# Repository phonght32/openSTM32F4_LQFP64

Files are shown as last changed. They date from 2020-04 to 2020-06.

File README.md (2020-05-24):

# openSTM32F4_LQFP64

### 1. Overview

Everything about this board: schematic, PCB gerber and BOM are free to distribute under open-source license for users.

The STM32F4 series chip inside openSTM32 board is based on ARM Cortex-M4 with floating point unit (FPU).

### 2. Specifications

| Items | Specifications |
| --- | --- |
| Power supply | 5V micro USB<br />5~36V Jack DC |
| Microcontroller | STM32F405RGT6 / 32-bit ARM Cortex-M4 with FPU(168MHz, 225DMIPS) |
| Sensors | 3 axis gyroscope, 3 axis accelerometer, 3 axis magnetometer (MPU9250) |
| Programmer | JTAG/SWD connector<br />Serial (UART3) |
| Communicaton Ports  | UART x 3<br />I2C x 1<br />SPI x 1 |
| Multimedia | I2S x 1 |
| Analog input | ADC channel x 5 |
| Analog output | DAC channel x 1 |
| PWM | Timer PWM x 4 |
| Leds and buttons | D7 and D8: USB communication<br />D6: 3V3 power on<br />D1: USER LED status<br />SW2: Reset button<br />SW1: USER button |
| Digital I/O | 10 pins |
| Output power source | 5V max 3A (TPS5430 step-down converter)<br />3V3 max 1A (AMS1117 linear regulator) |
| Dimensions | 68 x 64 mm |

**NOTE:**

This board auto select power supply when both USB and jackDC are powered.

### 3. Layout / Pin map

### 4. Hardware design

#### Schematic

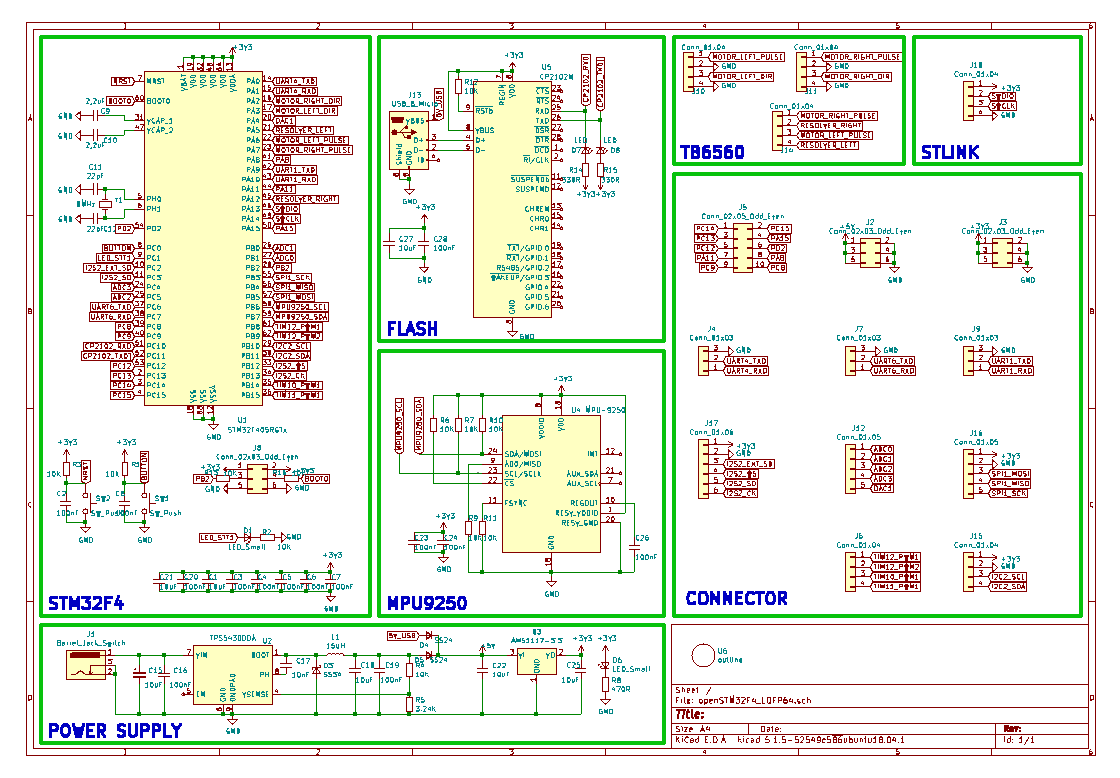
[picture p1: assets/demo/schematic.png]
schematic


#### Dimension

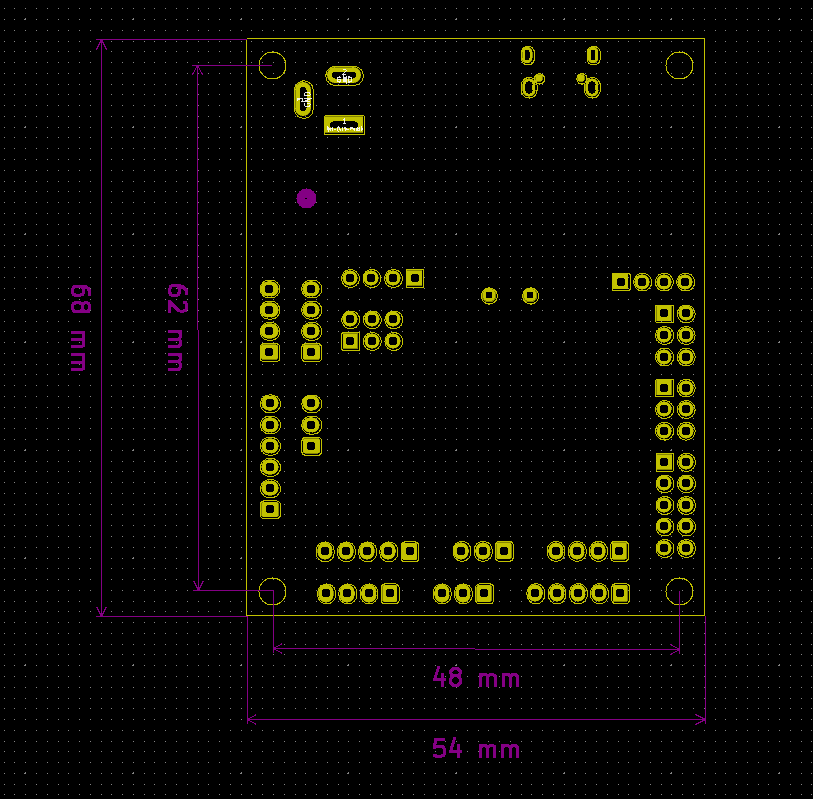
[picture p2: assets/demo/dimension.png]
dimension


#### PCB Top

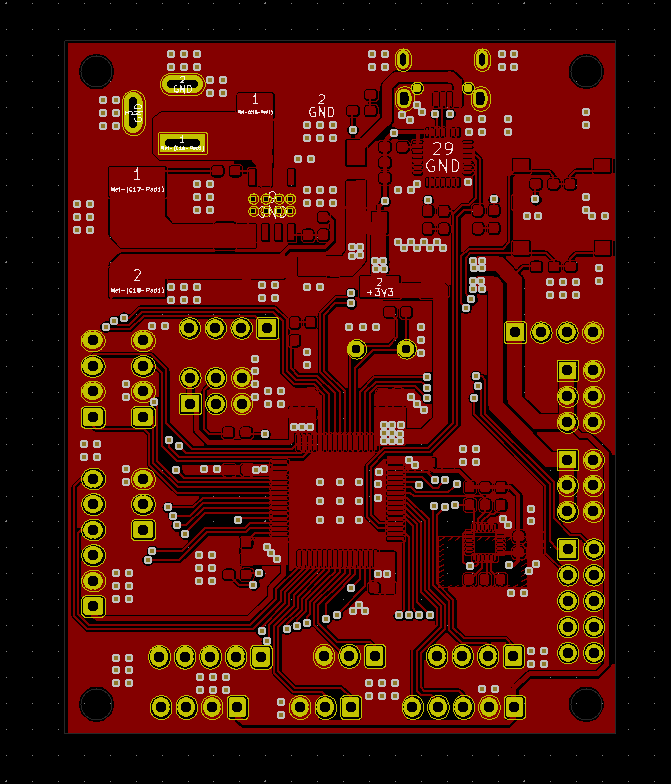
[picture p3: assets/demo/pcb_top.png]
pcb_top


#### PCB Bot

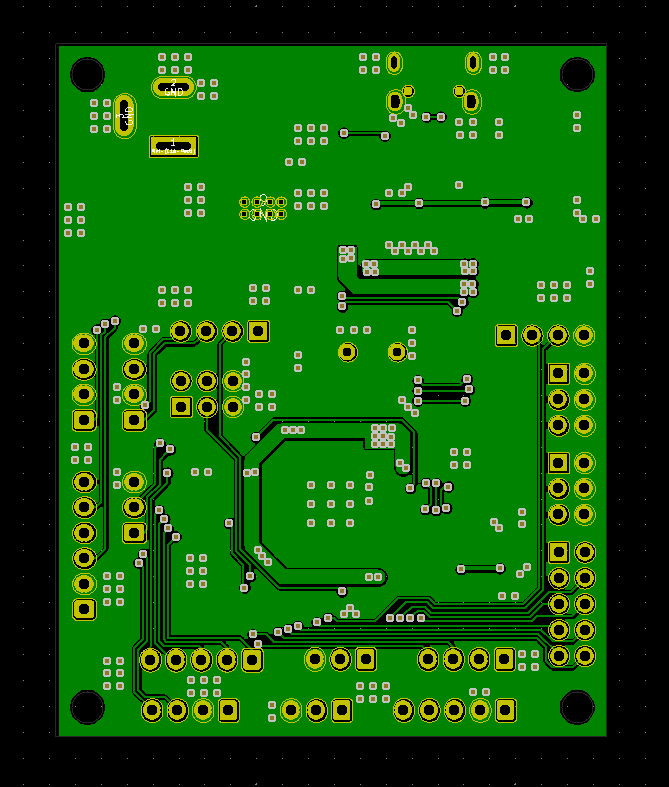
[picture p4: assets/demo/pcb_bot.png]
pcb_bot


#### 3D Top

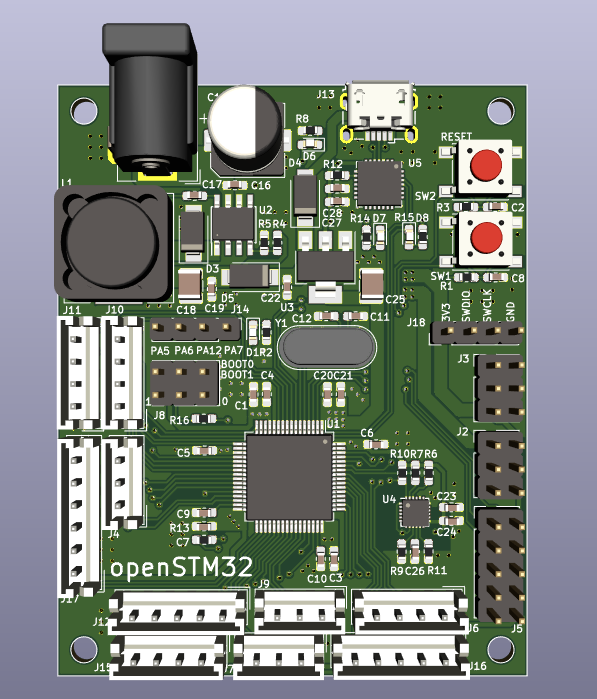
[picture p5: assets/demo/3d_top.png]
3d_top


#### 3D Bot

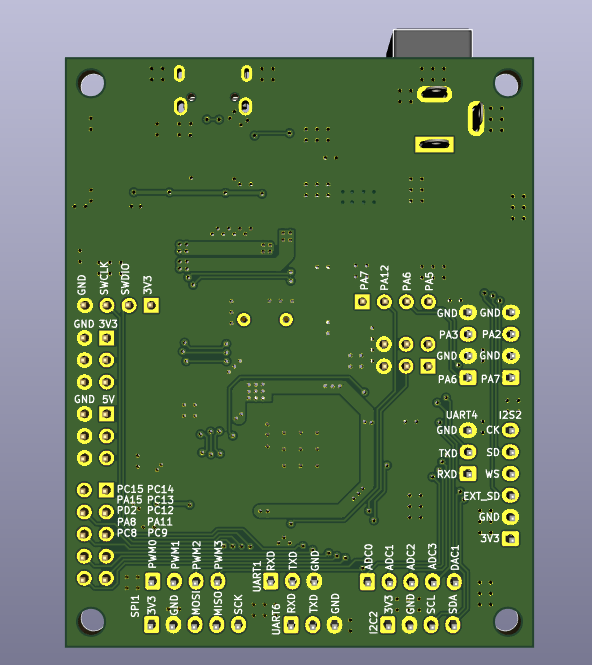
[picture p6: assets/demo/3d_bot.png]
3d_bot


### 5. Bill of Materials (BOM)

Download BOM [here.](assets/bom.xlsx)

### 6. Gerber

Download PCB gerber [here.](assets/openSTM32_68x54mm.zip)

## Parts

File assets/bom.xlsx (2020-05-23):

Source: | /home/phong/Documents/thesis/openSTM32F4_LQFP64/openSTM32F4_LQFP64.sch
Date: | Thứ bảy, 23 Tháng năm Năm 2020 22:04:47 +07
Tool: | Eeschema 5.1.6-c6e7f7d~86~ubuntu16.04.1
Generator: | /usr/share/kicad/plugins/bom_csv_grouped_by_value_with_fp.py
Component Count: | 77
Ref | Qnty | Value | Cmp name | Footprint | Description | Vendor
C1, C21, C22, C27, | 4 | 10uF | C_Small | Capacitor_SMD:C_0603_1608Metric_Pad1.05x0.95mm_HandSolder | Unpolarized capacitor, small symbol
C2, C3, C4, C5, C6, C7, C8, C16, C19, C20, C23, C24, C26, C28, | 14 | 100nF | C_Small | Capacitor_SMD:C_0603_1608Metric_Pad1.05x0.95mm_HandSolder | Unpolarized capacitor, small symbol
C9, C10, | 2 | 2,2uF | C_Small | Capacitor_SMD:C_0603_1608Metric_Pad1.05x0.95mm_HandSolder | Unpolarized capacitor, small symbol
C11, C12, | 2 | 22pF | C_Small | Capacitor_SMD:C_0603_1608Metric_Pad1.05x0.95mm_HandSolder | Unpolarized capacitor, small symbol
C15, | 1 | 10uF | CP_Small | Capacitor_SMD:CP_Elec_8x10 | Polarized capacitor, small symbol
C17, | 1 | 10nF | C_Small | Capacitor_SMD:C_0603_1608Metric_Pad1.05x0.95mm_HandSolder | Unpolarized capacitor, small symbol
C18, C25, | 2 | 10uF | C_Small | Capacitor_SMD:C_1210_3225Metric | Unpolarized capacitor, small symbol
D1, D6, | 2 | LED_Small | LED_Small | LED_SMD:LED_0603_1608Metric_Pad1.05x0.95mm_HandSolder | Light emitting diode, small symbol
D3, | 1 | SS34 | D_Schottky_Small | Diode_SMD:D_SMA | Schottky diode, small symbol
D4, D5, | 2 | SS24 | D_Small | Diode_SMD:D_SMA | Diode, small symbol
D7, D8, | 2 | LED | LED_Small | LED_SMD:LED_0603_1608Metric_Pad1.05x0.95mm_HandSolder | Light emitting diode, small symbol
J1, | 1 | Barrel_Jack_Switch | Barrel_Jack_Switch | Connector_BarrelJack:BarrelJack_Wuerth_6941xx301002 | DC Barrel Jack with an internal switch
J2, J3, J8, | 3 | Conn_02x03_Odd_Even | Conn_02x03_Odd_Even | Connector_PinHeader_2.54mm:PinHeader_2x03_P2.54mm_Vertical | Generic connector, double row, 02x03, odd/even pin numbering scheme (row 1 odd numbers, row 2 even numbers), script generated (kicad-library-utils/schlib/autogen/connector/)
J4, J7, J9, | 3 | Conn_01x03 | Conn_01x03 | Connector_JST:JST_EH_B3B-EH-A_1x03_P2.50mm_Vertical | Generic connector, single row, 01x03, script generated (kicad-library-utils/schlib/autogen/connector/)
J5, | 1 | Conn_02x05_Odd_Even | Conn_02x05_Odd_Even | Connector_PinHeader_2.54mm:PinHeader_2x05_P2.54mm_Vertical | Generic connector, double row, 02x05, odd/even pin numbering scheme (row 1 odd numbers, row 2 even numbers), script generated (kicad-library-utils/schlib/autogen/connector/)
J6, J10, J11, J15, | 4 | Conn_01x04 | Conn_01x04 | Connector_JST:JST_EH_B4B-EH-A_1x04_P2.50mm_Vertical | Generic connector, single row, 01x04, script generated (kicad-library-utils/schlib/autogen/connector/)
J12, J16, | 2 | Conn_01x05 | Conn_01x05 | Connector_JST:JST_EH_B5B-EH-A_1x05_P2.50mm_Vertical | Generic connector, single row, 01x05, script generated (kicad-library-utils/schlib/autogen/connector/)
J13, | 1 | USB_B_Micro | USB_B_Micro | Connector_USB:USB_Micro-B_Wuerth_629105150521 | USB Micro Type B connector
J14, J18, | 2 | Conn_01x04 | Conn_01x04 | Connector_PinHeader_2.54mm:PinHeader_1x04_P2.54mm_Vertical | Generic connector, single row, 01x04, script generated (kicad-library-utils/schlib/autogen/connector/)
J17, | 1 | Conn_01x06 | Conn_01x06 | Connector_JST:JST_EH_B6B-EH-A_1x06_P2.50mm_Vertical | Generic connector, single row, 01x06, script generated (kicad-library-utils/schlib/autogen/connector/)
L1, | 1 | 15uH | L_Small | Inductor_SMD:L_12x12mm_H6mm | Inductor, small symbol
R1, R2, R3, R4, R6, R7, R9, R10, R11, R12, R13, R16, | 12 | 10K | R_Small | Resistor_SMD:R_0603_1608Metric_Pad1.05x0.95mm_HandSolder | Resistor, small symbol
R5, | 1 | 3.24K | R_Small | Resistor_SMD:R_0603_1608Metric_Pad1.05x0.95mm_HandSolder | Resistor, small symbol
R8, | 1 | 470R | R_Small | Resistor_SMD:R_0603_1608Metric_Pad1.05x0.95mm_HandSolder | Resistor, small symbol
R14, R15, | 2 | 330R | R_Small | Resistor_SMD:R_0603_1608Metric_Pad1.05x0.95mm_HandSolder | Resistor, small symbol
SW1, SW2, | 2 | SW_Push | SW_Push | Button_Switch_SMD:SW_Push_1P1T_NO_6x6mm_H9.5mm | Push button switch, generic, two pins
U1, | 1 | STM32F405RGTx | STM32F405RGTx | Package_QFP:LQFP-64_10x10mm_P0.5mm | ARM Cortex-M4 MCU, 1024KB flash, 128KB RAM, 168MHz, 1.8-3.6V, 51 GPIO, LQFP-64
U2, | 1 | TPS5430DDA | TPS5430DDA | Package_SO:TI_SO-PowerPAD-8_ThermalVias | 3A, Step Down Swift Converter, Adjustable Output Voltage, 5.5-36V Input Voltage, PowerSO-8
U3, | 1 | AMS1117-3.3 | AMS1117-3.3 | Package_TO_SOT_SMD:SOT-223-3_TabPin2 | 1A Low Dropout regulator, positive, 3.3V fixed output, SOT-223
U4, | 1 | MPU-9250 | MPU-9250 | Sensor_Motion:InvenSense_QFN-24_3x3mm_P0.4mm | InvenSense 9-Axis Motion Sensor, Accelerometer, Gyroscope, Compass, I2C/SPI
U5, | 1 | CP2102N | CP2102N-A01-GQFN28 | Package_DFN_QFN:QFN-28-1EP_5x5mm_P0.5mm_EP3.35x3.35mm | USB to UART master bridge, QFN-28
U6, | 1 | outline | outline | footprints:openSTM32F4_LQFP64_outline
Y1, | 1 | 8MHz | Crystal_Small | Crystal:Crystal_HC49-4H_Vertical | Two pin crystal, small symbol

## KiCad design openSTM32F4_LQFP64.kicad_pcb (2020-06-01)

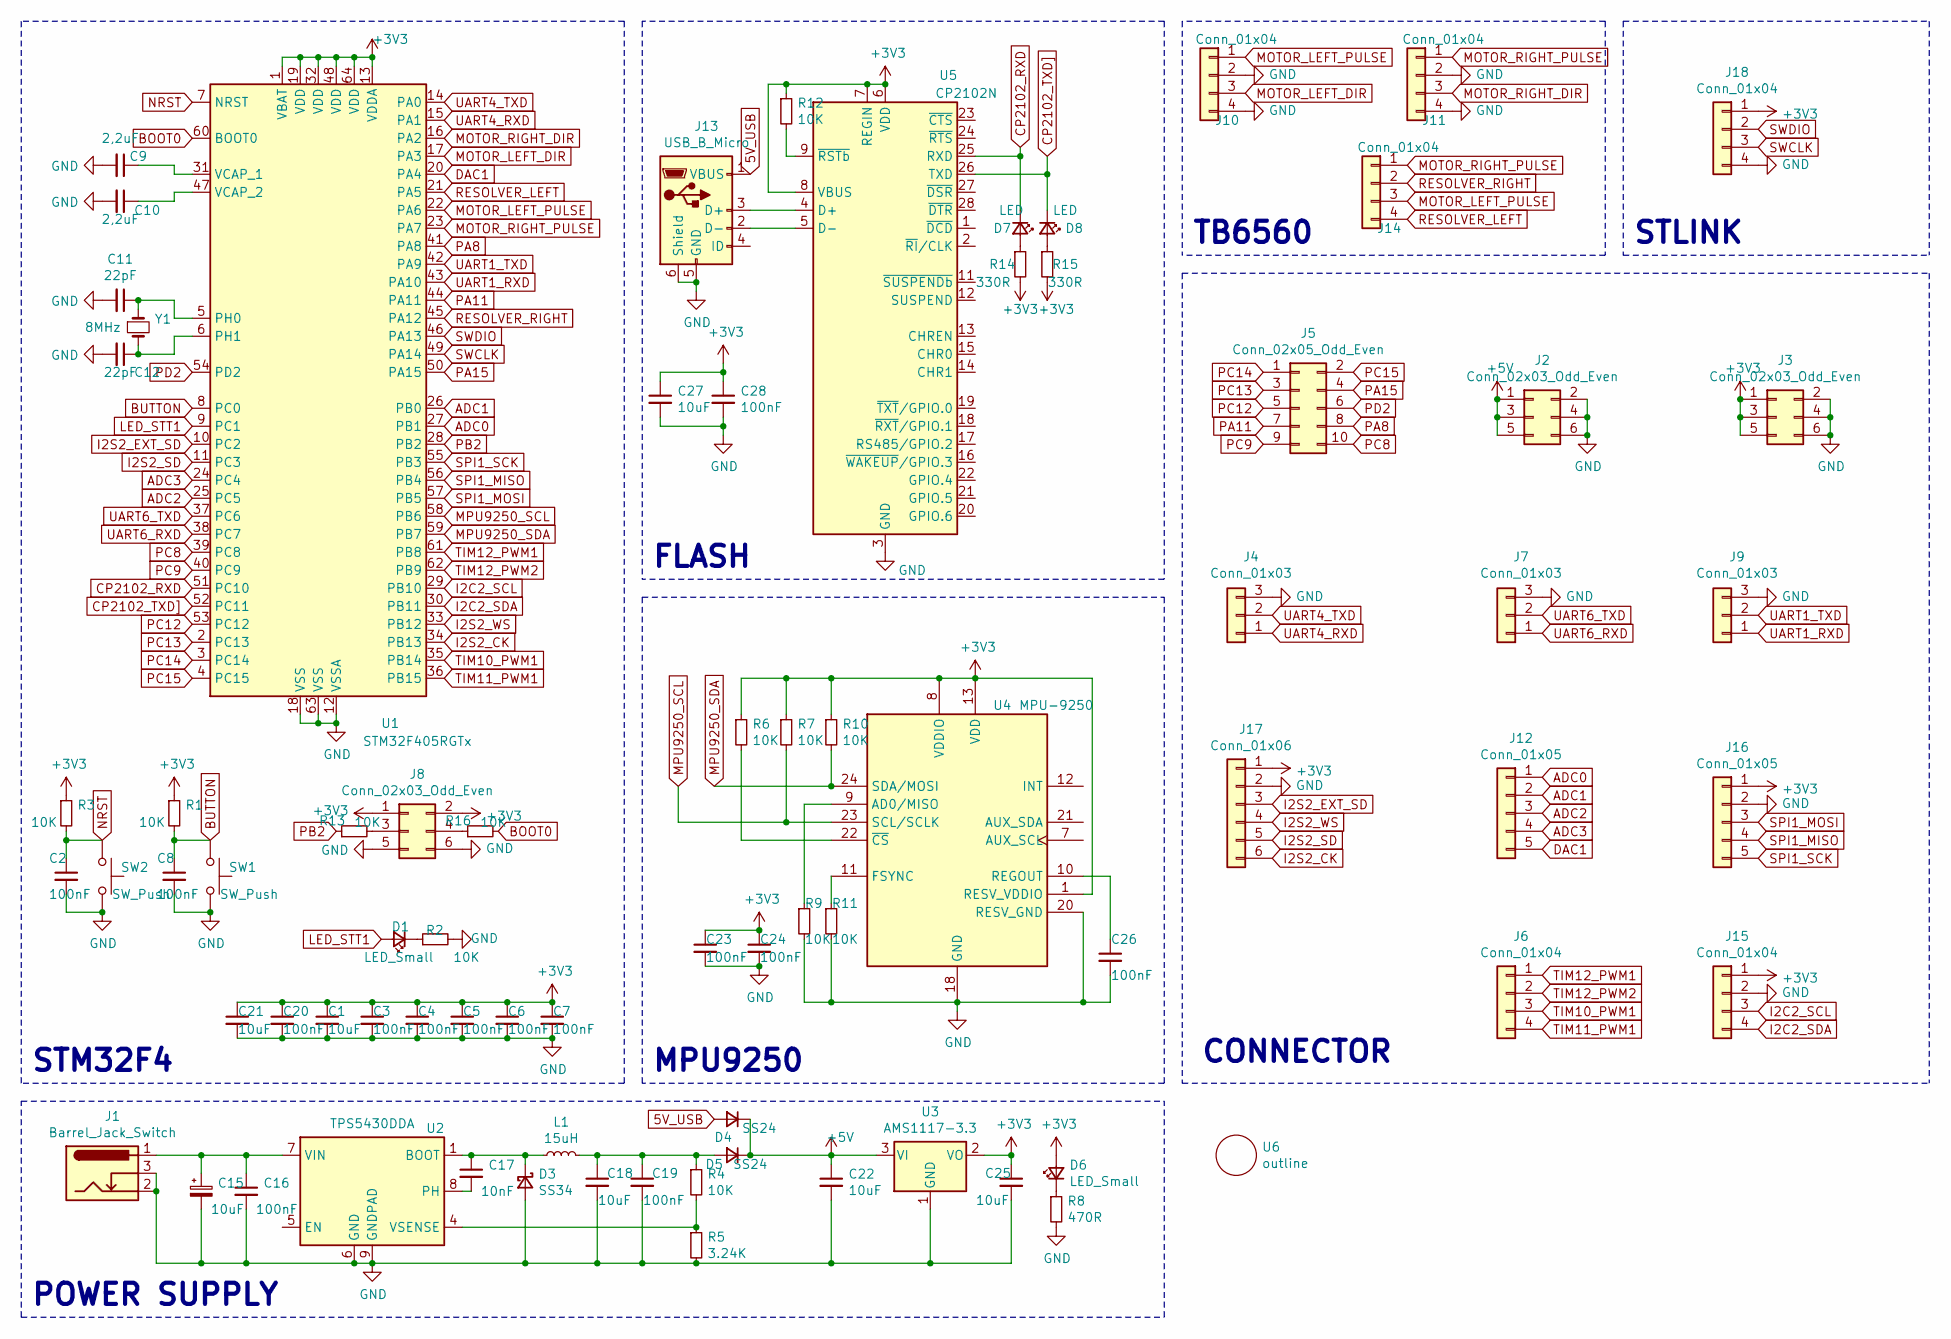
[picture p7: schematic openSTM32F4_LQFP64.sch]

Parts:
C1, C21, C22, C27: 10uF; C_0603_1608Metric_Pad1.05x0.95mm_HandSolder
C2, C3, C4, C5, C6, C7, C8, C16, C19, C20, C23, C24, C26, C28: 100nF; C_0603_1608Metric_Pad1.05x0.95mm_HandSolder
C9, C10: 2,2uF; C_0603_1608Metric_Pad1.05x0.95mm_HandSolder
C11, C12: 22pF; C_0603_1608Metric_Pad1.05x0.95mm_HandSolder
C15: 10uF; CP_Elec_8x10
C17: 10nF; C_0603_1608Metric_Pad1.05x0.95mm_HandSolder
C18, C25: 10uF; C_1210_3225Metric
D1, D6: LED_Small; LED_0603_1608Metric_Pad1.05x0.95mm_HandSolder
D3: SS34; D_SMA
D4, D5: SS24; D_SMA
D7, D8: LED; LED_0603_1608Metric_Pad1.05x0.95mm_HandSolder
J1: Barrel_Jack_Switch; BarrelJack_Wuerth_6941xx301002
J2, J3, J8: Conn_02x03_Odd_Even; PinHeader_2x03_P2.54mm_Vertical
J4, J7, J9: Conn_01x03; JST_EH_B3B-EH-A_1x03_P2.50mm_Vertical
J5: Conn_02x05_Odd_Even; PinHeader_2x05_P2.54mm_Vertical
J6, J10, J11, J15: Conn_01x04; JST_EH_B4B-EH-A_1x04_P2.50mm_Vertical
J12, J16: Conn_01x05; JST_EH_B5B-EH-A_1x05_P2.50mm_Vertical
J13: USB_B_Micro; USB_Micro-B_Wuerth_629105150521
J14, J18: Conn_01x04; PinHeader_1x04_P2.54mm_Vertical
J17: Conn_01x06; JST_EH_B6B-EH-A_1x06_P2.50mm_Vertical
L1: 15uH; L_12x12mm_H6mm
R1, R2, R3, R4, R6, R7, R9, R10, R11, R12, R13, R16: 10K; R_0603_1608Metric_Pad1.05x0.95mm_HandSolder
R5: 3.24K; R_0603_1608Metric_Pad1.05x0.95mm_HandSolder
R8: 470R; R_0603_1608Metric_Pad1.05x0.95mm_HandSolder
R14, R15: 330R; R_0603_1608Metric_Pad1.05x0.95mm_HandSolder
SW1, SW2: SW_Push; SW_Push_1P1T_NO_6x6mm_H9.5mm
U1: STM32F405RGTx; LQFP-64_10x10mm_P0.5mm
U2: TPS5430DDA; TI_SO-PowerPAD-8_ThermalVias
U3: AMS1117-3.3; SOT-223-3_TabPin2
U4: MPU-9250; MPU9250
U5: CP2102N; QFN-28-1EP_5x5mm_P0.5mm_EP3.35x3.35mm
U6: outline; openSTM32F4_LQFP64_outline
Y1: 8MHz; Crystal_HC49-4H_Vertical

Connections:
5V_USB: D4.2 (A), J13.1 (VBUS)
+3V3: C1.1, C3.1, C4.1, C5.1, C6.1, C7.1, C20.1, C21.1, C23.1, C24.1, C25.1, C27.1, C28.1, D6.2 (A), J3.1, J3.3, J3.5, J8.1, J8.2, J15.1, J16.1, J17.1, J18.1, R1.1, R3.1, R6.1, R7.1, R10.1, R12.1, R14.2, R15.2, U1.1 (VBAT), U1.13 (VDDA), U1.19 (VDD), U1.32 (VDD), U1.48 (VDD), U1.64 (VDD), U3.2 (VO), U4.1 (RESV_VDDIO), U4.8 (VDDIO), U4.13 (VDD), U5.6 (VDD), U5.7 (REGIN), U5.8 (VBUS)
+5V: C22.1, D4.1 (K), D5.1 (K), J2.1, J2.3, J2.5, U3.3 (VI)
ADC0: J12.1, U1.27 (PB1)
ADC1: J12.2, U1.26 (PB0)
ADC2: J12.3, U1.25 (PC5)
ADC3: J12.4, U1.24 (PC4)
BOOT0: R16.2, U1.60 (BOOT0)
BUTTON: C8.1, R1.2, SW1.1, U1.8 (PC0)
CP2102_RXD: D7.1 (K), U1.51 (PC10), U5.25 (RXD)
CP2102_TXD]: D8.1 (K), U1.52 (PC11), U5.26 (TXD)
DAC1: J12.5, U1.20 (PA4)
GND: C1.2, C2.2, C3.2, C4.2, C5.2, C6.2, C7.2, C8.2, C9.2, C10.2, C11.2, C12.2, C15.2, C16.2, C18.2, C19.2, C20.2, C21.2, C22.2, C23.2, C24.2, C25.2, C26.2, C27.2, C28.2, D3.2 (A), J1.2, J1.3, J2.2, J2.4, J2.6, J3.2, J3.4, J3.6, J4.3, J7.3, J8.5, J8.6, J9.3, J10.2, J10.4, J11.2, J11.4, J13.5 (GND), J13.6 (Shield), J15.2, J16.2, J17.2, J18.4, R2.2, R5.2, R8.2, R9.2, R11.2, SW1.2, SW2.2, U1.12 (VSSA), U1.18 (VSS), U1.63 (VSS), U2.6 (GND), U2.9 (GNDPAD), U3.1 (GND), U4.18 (GND), U4.20 (RESV_GND), U4.GND, U5.3 (GND), U5.29 (GND)
I2C2_SCL: J15.3, U1.29 (PB10)
I2C2_SDA: J15.4, U1.30 (PB11)
I2S2_CK: J17.6, U1.34 (PB13)
I2S2_EXT_SD: J17.3, U1.10 (PC2)
I2S2_SD: J17.5, U1.11 (PC3)
I2S2_WS: J17.4, U1.33 (PB12)
LED_STT1: D1.2 (A), U1.9 (PC1)
MOTOR_LEFT_DIR: J10.3, U1.17 (PA3)
MOTOR_LEFT_PULSE: J10.1, J14.3, U1.22 (PA6)
MOTOR_RIGHT_DIR: J11.3, U1.16 (PA2)
MOTOR_RIGHT_PULSE: J11.1, J14.1, U1.23 (PA7)
MPU9250_SCL: R7.2, U1.58 (PB6), U4.23 (SCL/SCLK)
MPU9250_SDA: R10.2, U1.59 (PB7), U4.24 (SDA/MOSI)
NRST: C2.1, R3.2, SW2.1, U1.7 (NRST)
unnamed: C9.1, U1.31 (VCAP_1)
unnamed: C10.1, U1.47 (VCAP_2)
unnamed: C11.1, U1.5 (PH0), Y1.1
unnamed: C12.1, U1.6 (PH1), Y1.2
unnamed: C15.1, C16.1, J1.1, U2.7 (VIN)
unnamed: C17.1, D3.1 (K), L1.1, U2.1 (BOOT)
unnamed: C17.2, U2.8 (PH)
unnamed: C18.1, C19.1, D5.2 (A), L1.2, R4.1
unnamed: C26.1, U4.10 (REGOUT)
unnamed: D1.1 (K), R2.1
unnamed: D6.1 (K), R8.1
unnamed: D7.2 (A), R14.1
unnamed: D8.2 (A), R15.1
unnamed: J8.3, R13.2
unnamed: J8.4, R16.1
unnamed: J13.2 (D-), U5.5 (D-)
unnamed: J13.3 (D+), U5.4 (D+)
unnamed: R4.2, R5.1, U2.4 (VSENSE)
unnamed: R6.2, U4.22 (~CS)
unnamed: R9.1, U4.9 (AD0/MISO)
unnamed: R11.1, U4.11 (FSYNC)
unnamed: R12.2, U5.9 (~RSTb)
PA8: J5.8, U1.41 (PA8)
PA11: J5.7, U1.44 (PA11)
PA15: J5.4, U1.50 (PA15)
PB2: R13.1, U1.28 (PB2)
PC8: J5.10, U1.39 (PC8)
PC9: J5.9, U1.40 (PC9)
PC12: J5.5, U1.53 (PC12)
PC13: J5.3, U1.2 (PC13)
PC14: J5.1, U1.3 (PC14)
PC15: J5.2, U1.4 (PC15)
PD2: J5.6, U1.54 (PD2)
RESOLVER_LEFT: J14.4, U1.21 (PA5)
RESOLVER_RIGHT: J14.2, U1.45 (PA12)
SPI1_MISO: J16.4, U1.56 (PB4)
SPI1_MOSI: J16.3, U1.57 (PB5)
SPI1_SCK: J16.5, U1.55 (PB3)
SWCLK: J18.3, U1.49 (PA14)
SWDIO: J18.2, U1.46 (PA13)
TIM10_PWM1: J6.3, U1.35 (PB14)
TIM11_PWM1: J6.4, U1.36 (PB15)
TIM12_PWM1: J6.1, U1.61 (PB8)
TIM12_PWM2: J6.2, U1.62 (PB9)
UART1_RXD: J9.1, U1.43 (PA10)
UART1_TXD: J9.2, U1.42 (PA9)
UART4_RXD: J4.1, U1.15 (PA1)
UART4_TXD: J4.2, U1.14 (PA0)
UART6_RXD: J7.1, U1.38 (PC7)
UART6_TXD: J7.2, U1.37 (PC6)

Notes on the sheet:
STM32F4
FLASH
MPU9250
POWER SUPPLY
TB6560
CONNECTOR
STLINK

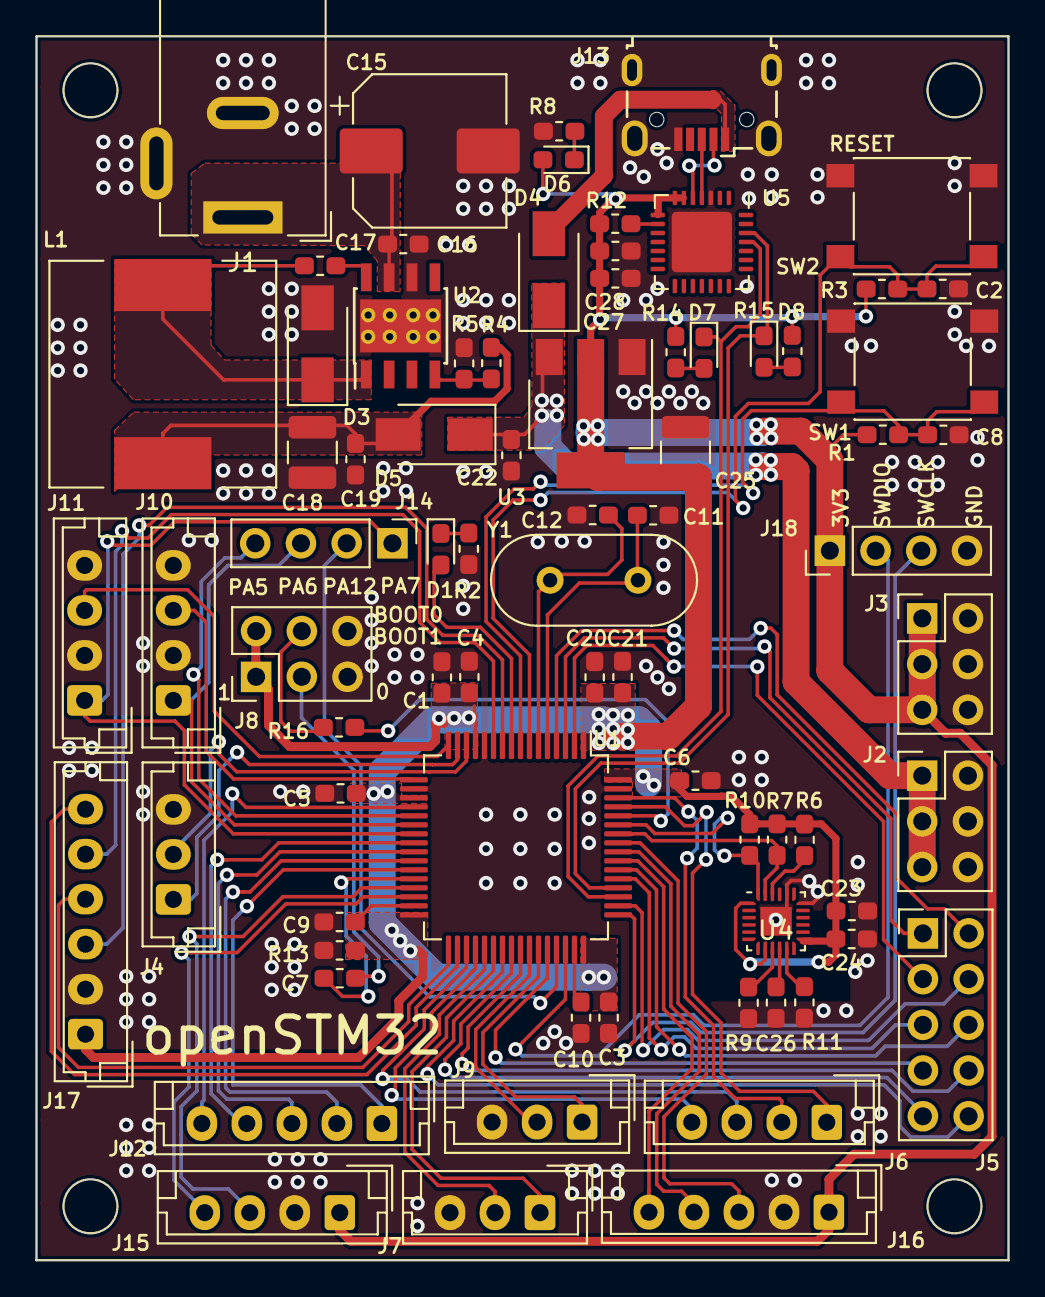
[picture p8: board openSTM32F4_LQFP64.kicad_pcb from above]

Board: 2 copper layers, 54.0 x 68.0 mm, 77 parts (0 on the bottom side), 77 nets.

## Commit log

2020-04-25 update jackDC mounting pin
    [openSTM32F4_LQFP64.sch]
2020-04-25 update gnd via
    [openSTM32F4_LQFP64.kicad_pcb]
2020-05-16 update gerber
    [openSTM32F4_LQFP64-B_Cu.gbr, openSTM32F4_LQFP64-B_Mask.gbr, openSTM32F4_LQFP64-B_Paste.gbr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]
2020-05-18 update via size
    [openSTM32F4_LQFP64-B_Cu.gbr, openSTM32F4_LQFP64-B_Mask.gbr, openSTM32F4_LQFP64-B_Paste.gbr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]
2020-05-23 add bom
    [bom.xlsx]
2020-05-31 add mpu9250 footprint
2020-05-31 fix mpu9250 thermal pad
    [openSTM32F4_LQFP64.kicad_pcb, openSTM32F4_LQFP64.sch]
2020-06-01 update mpu9250 footprint
    [openSTM32F4_LQFP64.kicad_pcb, openSTM32F4_LQFP64.sch]
